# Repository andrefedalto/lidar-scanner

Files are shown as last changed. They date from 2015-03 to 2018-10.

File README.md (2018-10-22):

Demo: https://www.youtube.com/watch?v=kJW9Uy4j-6k

# Introduction
The goal of this project was to use a rangefinder mounted in servos, which would rotate and allow it to measure different parts of the room. The angles and distances are sent in real time to the computer that reads, converts and creates a 3D scene of the place. In the end, it works like a 3D scanner of the room and any object inside.

We first tried using a sonar rangefinder to make the distance measurements, but even using a sonar with a narrow beam, it was not narrow enough to make precise readings. Furthermore, the waves emitted by the sonar would bounce on angled surfaces and give wrong readings. To overcome this problem we used a LIDAR (laser-based range finder), which is very accurate, has an extremely narrow beam and won’t bounce off surfaces. The only downside is that it is not so precise with shiny surfaces and cannot make readings against transparent surfaces, such as windows, but it is good enough for the purpose we need.

# The Project
The project can be roughly divided in three parts: electronics, arduino programming and the interface programming.

## Electronics
To build the prototype we used two servo motors (model HS-422), which are capable of rotating 180 degrees and keep track of their position. As the rangefinder we used a LIDAR-Lite, the most affordable LIDAR we were able to find, but still an excellent product for its price. Everything was powered by power bank and controlled by an arduino. The schematics can be found in our blog.

## Arduino
The code run by the arduino is pretty straightforward. It moves the servos (keeping track of its position) and reads the distance from the sensor after every movement. Every time it reads the distance, a string is sent through the serial port with information from the distance and the servos position. One of the problems encountered was that reading from the sensor inside nested loops would create unexpected behaviour of arduino, so the logic had to be changed to iterate over servos position using only the arduino built-in loop() function.

## Interface
The computer interface for the prototype, written using C++ and OpenGL, reads the data sent by the arduino, analyses, convert to Cartesian coordinates and plots to the screen. Each point is created in the screen as a cube with its colour varying depending on distance and angles. The interface is also responsible to communicate with arduino and send a starting code, telling the prototype to start scanning. All the scans are shown in the screen in real time, as the distances are being read and transmitted. It is possible to navigate in the 3D view while the scanning is taking progress. The software allows saving the scan to a file and loading it later. A preview of the saved files is available to make it easy to select the desired scan.

# Links
During the development we maintained a weekly report in the project blog. More info can be found there, and also links to our presentation, the github repository for the code and also a time-lapse video with the working prototype.
http://lidarscanner.wordpress.com

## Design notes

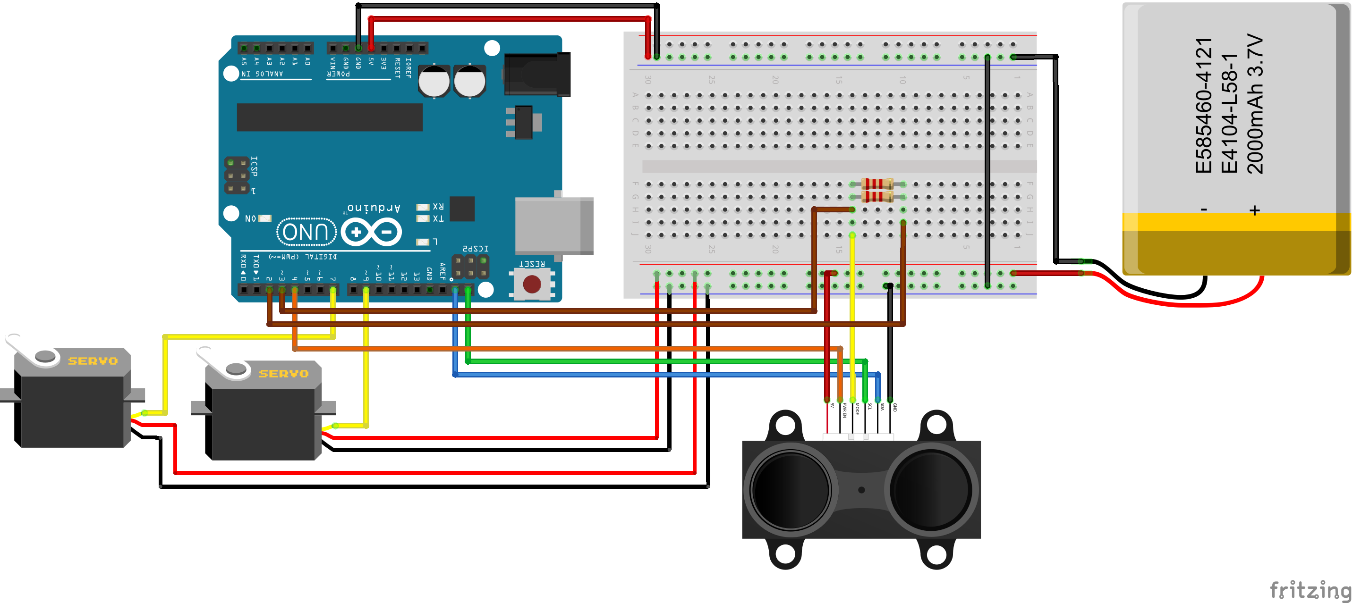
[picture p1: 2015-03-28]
schematics/finalProject_bb.png

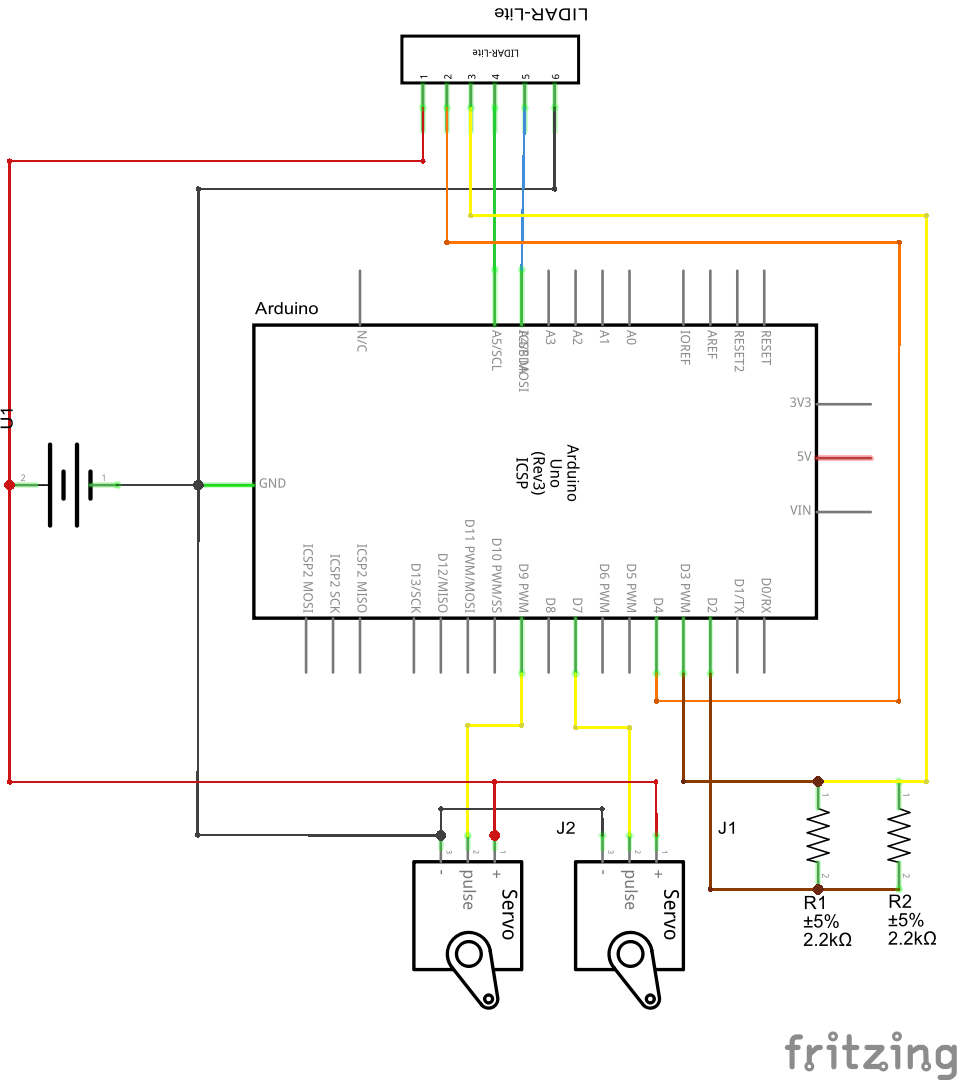
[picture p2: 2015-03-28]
schematics/finalProject_schem.png

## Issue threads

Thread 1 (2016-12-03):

Use case for mapping outdoor objects like cars and streets

itissid, 2016-12-03:
Hi would you think using this project one could accurately measure stationary objects on the road like cars? I am not looking to mount this set up on a car and drive around. Instead just place it outdoors and get a map of objects on the street in a reasonable amount of time (Of course assume the objects are 30-40 meters away from the sensor)?

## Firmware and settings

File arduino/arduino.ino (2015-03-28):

#include <Servo.h> 
#include <I2C.h>

#define    LIDARLite_ADDRESS   0x62          // Default I2C Address of LIDAR-Lite.
#define    RegisterMeasure     0x00          // Register to write to initiate ranging.
#define    MeasureValue        0x04          // Value to initiate ranging.
#define    RegisterHighLowB    0x8f          // Register to get both High and Low bytes in 1 call.

Servo servoRotate;
Servo servoScan;

int servoRotatePosition = 0;
int servoScanPosition = 0;

int servoRotateDirection = 1;
int servoScanDirection = 1;

int sensorEnablePin = 4;

int distance;

void setup() 
{ 
  servoRotate.attach(9);  //Servo making the pan movement
  servoScan.attach(7);    //Servo making the tilt movement

  Serial.begin(9600); 

  //Joining the I2C bus
  I2c.begin();
  delay(100);
  I2c.timeOut(50);
  
  //Enabling the sensor
  pinMode(sensorEnablePin, OUTPUT);
  digitalWrite(sensorEnablePin, HIGH); // Set trigger LOW for continuous read

  //Moving the servo to create some nice moving effect when the scan starts
  servoRotate.write(180);
  servoScan.write(180);
  delay(1000);
  
  //Keep pooling the serial buffer until any command is received from the PC
  while (!Serial.available()) {}
  
  //Moving to initial position
  servoRotate.write(servoRotatePosition);
  servoScan.write(servoScanPosition);
  delay(1000);
} 
 
void loop() 
{ 

  //Limit to only one scan, for more the program (or the arduino) must be restarted
  if (servoScanPosition <= 180)
  {

    servoRotate.write(servoRotatePosition);
    servoScan.write(servoScanPosition);
    
    
    // Based on example code from https://github.com/PulsedLight3D/

    // Write 0x04 to register 0x00
    uint8_t nackack = 100; // Setup variable to hold ACK/NACK resopnses     
    while (nackack != 0){ // While NACK keep going (i.e. continue polling until sucess message (ACK) is received )
      nackack = I2c.write(LIDARLite_ADDRESS,RegisterMeasure, MeasureValue); // Write 0x04 to 0x00
      delay(1); // Wait 1 ms to prevent overpolling
    }
  
    byte distanceArray[2]; // array to store distance bytes from read function
    
    // Read 2byte distance from register 0x8f
    nackack = 100; // Setup variable to hold ACK/NACK resopnses     
    while (nackack != 0){ // While NACK keep going (i.e. continue polling until sucess message (ACK) is received )
      nackack = I2c.read(LIDARLite_ADDRESS,RegisterHighLowB, 2, distanceArray); // Read 2 Bytes from LIDAR-Lite Address and store in array
      delay(1); // Wait 1 ms to prevent overpolling
    }
    distance = (distanceArray[0] << 8) + distanceArray[1];  // Shift high byte [0] 8 to the left and add low byte [1] to create 16-bit int
    
    
    // Print Distance
    printOutput(servoRotatePosition, servoScanPosition, distance);
  
    
    // Pooling the sensor from inside nested loops was giving bugs and freezing the loops
    // The following code will make both servos move using only the built-in arduino loop()
    
    //Making the pan servo move both ways
    if (servoRotateDirection == 1)
      servoRotatePosition++;
    else
      servoRotatePosition--;
  
  
    //Changing the direction in the edges
    //Moving the tilt servo only when the pan reaches each side
    if (servoRotatePosition == 180 || servoRotatePosition == 0)
    {
      servoRotateDirection = -servoRotateDirection;
      servoScanPosition = (servoScanPosition + 1)%182;
    }  
  
    //Delay to allow servos moving and sensor reading  
    delay(20);

  }
} 

//We need a string with fixed length, so zeroes are added to the distances
void printOutput(int angleRotate, int angleScan, int distance)
{
  Serial.print("T");
  if (angleRotate < 10)
    Serial.print("00");
  else if (angleRotate < 100)
    Serial.print("0");
  Serial.print(angleRotate);
  
  Serial.print("P");
  if (angleScan < 10)
    Serial.print("00");
  else if (angleScan < 100)
    Serial.print("0");
  Serial.print(angleScan);
  
  Serial.print("V");
  if (distance < 10)
    Serial.print("000");
  else if (distance < 100)
    Serial.print("00");
  else if (distance < 1000)
    Serial.print("0");
  Serial.println(distance);
}

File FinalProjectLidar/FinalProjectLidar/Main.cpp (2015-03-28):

#ifdef SFML_STATIC
#pragma comment(lib, "glew.lib")
#pragma comment(lib, "freetype.lib")
#pragma comment(lib, "jpeg.lib")
#pragma comment(lib, "opengl32.lib")
#pragma comment(lib, "winmm.lib")
#pragma comment(lib, "gdi32.lib")  
#endif // SFML_STATIC


#include <vector>
#include <cmath>

#include <SFML/Graphics.hpp>
#include <SFML/OpenGL.hpp>
#include <SFML/Window.hpp>

#include "WindowManager.h"
#include "InputManager.h"
#include "Menu.h"

enum runStates { RUNNING, MENU, EXIT, SCAN };

int main()
{
	
	//Create a new window. Can be used both with OpenGL and SFML
	sf::RenderWindow window(sf::VideoMode(1000, 800, 32), "Lidar OpenGL");

	//Enable VerticalSync
	window.setVerticalSyncEnabled(true);

	InputManager input(&window);

	//Create a vector of cubes to be drawn on the main panel of the window
	std::vector<Cube> cubes;

	//Create an objec manager
	WindowManager manager(&window, &input, &cubes);

	

	//Call the setup, mostly for OpenGL and drawing the initial view
	manager.setup();

	//Create a menu
	Menu menu(&input, &window, &cubes);

	//Initial "runningState" set to Menu
	runStates state = MENU;
	manager.setOnMenu(true);
	menu.setRunning(true);


	// run the main loop
	bool running = true;
	
	//Code used to check Menu Actions
	int code = 200;

	//Set scanning mode to false
	bool scanning = false;

	while (running)
	{
		//Update objets
		manager.update();
		input.update();
		//Clear sceen
		glClear(GL_COLOR_BUFFER_BIT | GL_DEPTH_BUFFER_BIT);
		switch (state) {
			case RUNNING: 
				//Returning to Menu
				if (!manager.running())
				{
					manager.setOnMenu(true);
					state = MENU;
					menu.setRunning(true);
					break;
				}
				//Check if scanning
				if (scanning)
					input.readSerial(&cubes);


				//Draw all 3D objects
				manager.draw3D();
				break;
			case MENU: 
				//Check if user close the Menu
				if (!menu.getRunning())
				{
					manager.setOnMenu(false);
					state = RUNNING;
					break;
				}
				if (scanning)
					input.readSerial(&cubes);

				//Get the code from Menu to check user action
				code = menu.update();

				//Code 200: OK
				if (code == 200){
					manager.draw3D();
					manager.draw2D();

					menu.draw();			
				}
				//Code 1: Scan
				else if (code == 1)
				{
					cubes.clear();
					scanning = true;
				}
				break;
			case EXIT: 
				break;
		}
		if (input.getExit())
		{
			running = false;
		}


		//Swap buffers and display the backbuffer on the screen
		window.display();


	}



	return 0;
}

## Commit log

2015-03-28 arduino and schematics
    [finalProject.fzz]
2015-03-28 comments to arduino code
